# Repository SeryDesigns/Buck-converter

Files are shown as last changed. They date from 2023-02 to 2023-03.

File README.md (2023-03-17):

# Buck converter

## Project status 
Manufactured, assembled, not tested yet

## Project overview

Small synchronous buck converter PCB that can be used for small projects, the converter is based on RT6222D IC.
The input voltage can range from 4.3V to 18V, the output can be set between 0.6V to 8V.
The maximum output current is 2A though thermal dissipation should be taken into account.\
The switching frequancy of the converter is 1.4MHz.\
The IC has thermal protection in case it gets too hot, if junction temperature goes above 160°C it will shut down until the junction cools down by 20°C.

The dimension of the PCB are 33mm X 15mm, it is a 2 layers PCB with compoenents assembled only on the TOP layer

Top view - \
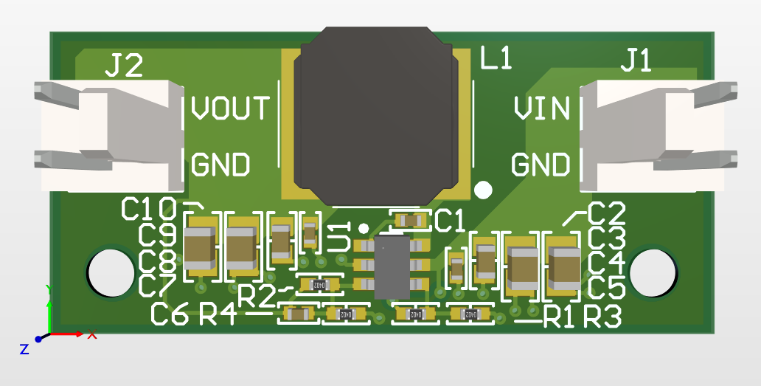
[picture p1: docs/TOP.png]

\
Bottom view -  \
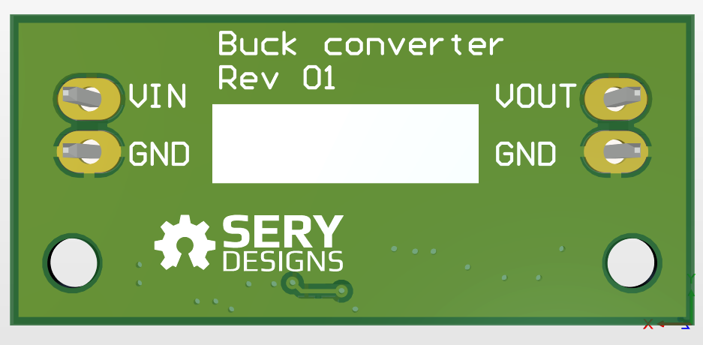
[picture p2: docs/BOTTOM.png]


I've created a short time lapse video of the design process, you can click the link below to check it out on my YouTube channel \
Buck converter PCB design in 5 minutes (time lapse) (https://youtu.be/Ut0V4XA0QD4)

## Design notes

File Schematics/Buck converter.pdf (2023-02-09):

# 12V to 5V buck converter

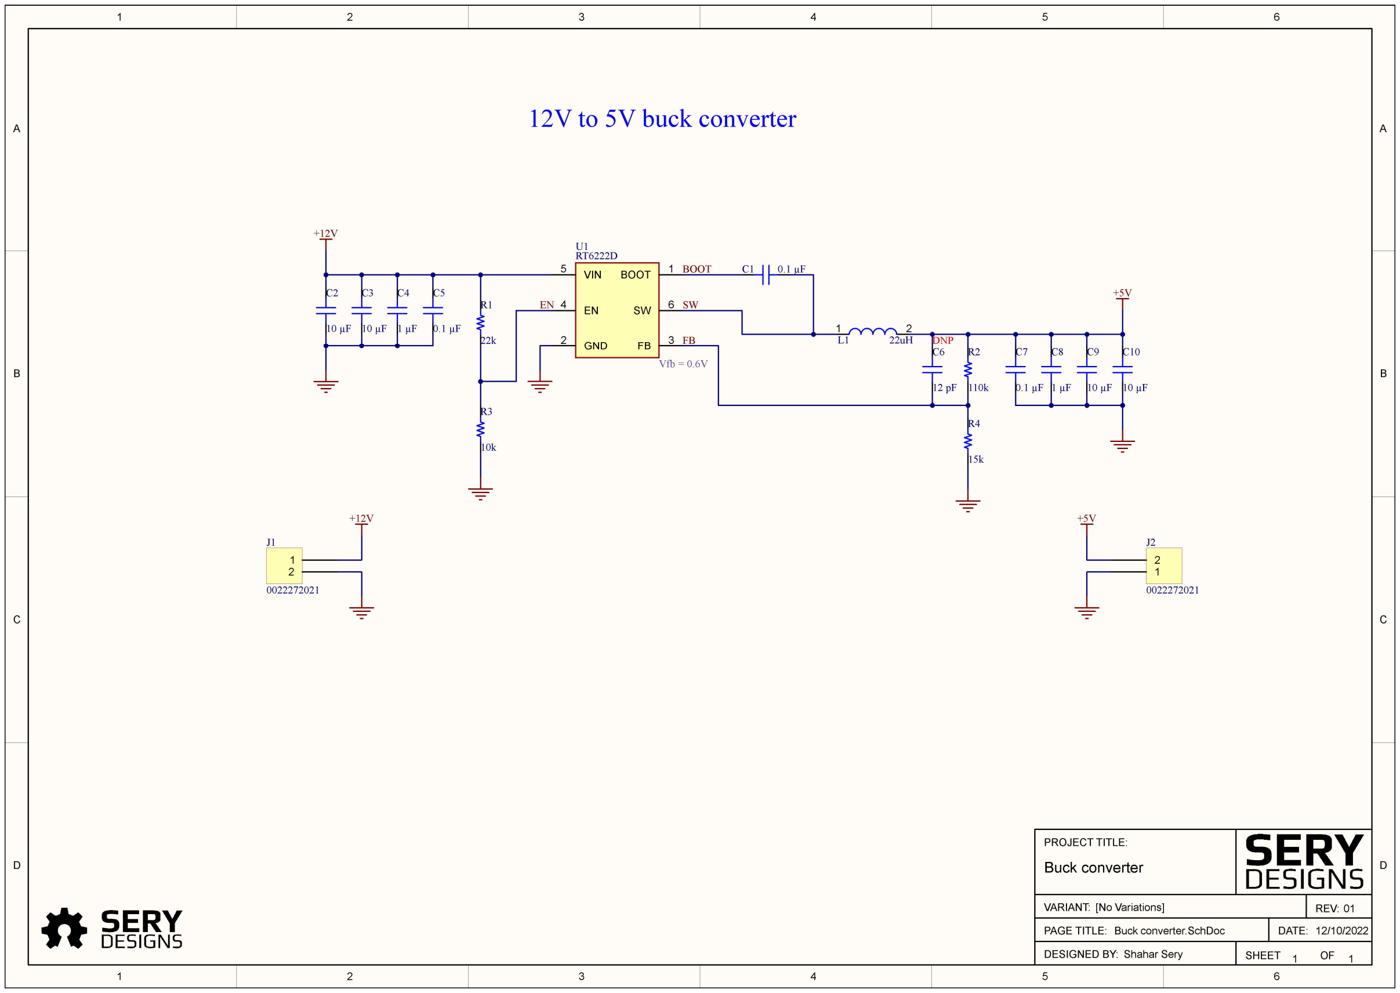
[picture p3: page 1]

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
Buck converter.SchDoc

SHEET | OF 1

REV:

PROJECT TITLE:

## Buck converter

1

VARIANT:

PAGE TITLE: | DATE:

DESIGNED BY:

[No Variations] | 01
| 12/10/2022

Shahar Sery

+12V

+5V

### 10 µF

C2

### 10 µF

C3

### 1 µF

C4

### 0.1 µF

C5

10k

R3

1 2
L1 | 22uH

15k

R4

110k

R2

### 10 µF

C10

### 10 µF

C9

### 1 µF

C8

### 0.1 µF

C7

C1 0.1 µF

### 12 pF

C6

EN

BOOT

SW

FB | DNP

1

2

J2

0022272021

1
2

J1

0022272021

+12V | +5V

Vfb = 0.6V

22k

R1

BOOT | 1
SW | 6

GND 2

EN 4

VIN 5

FB 3

U1
RT6222D

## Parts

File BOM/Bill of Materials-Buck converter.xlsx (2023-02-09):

Name | Designator | Description | Quantity | Manufacturer 1 | Manufacturer Part Number 1 | Manufacturer Lifecycle 1 | Supplier 1 | Supplier Part Number 1 | Supplier Unit Price 1 | Supplier Subtotal 1
0.1 µF | C1, C5, C7 | V | 3 |  |  |  | DigiKey | 490-GRT155R71H104KE01DCT-ND
10 µF | C2, C3, C9, C10 | V | 4 | Murata | GRM21BR61H106ME43L | Unknown | Digi-Key | 490-18664-1-ND | 0.35 | 1.4
1 µF | C4, C8 | V | 2 | Taiyo Yuden | UMK107AB7105KA-T | Unknown | Digi-Key | 587-3247-1-ND | 0.26 | 0.52
22uH | L1 | Inductor, Fixed, SMD, 22µH, 2.2A | 1 | Taiyo Yuden | NRS8040T220MJGJV | Unknown | Digi-Key | 587-3655-2-ND | 0.27472 | 274.72
22k | R1 | RES SMD 22K OHM 1% 1/16W 0402 | 1 | Bourns | CR0402-FX-2202GLF | Unknown | Digi-Key | CR0402-FX-2202GLFCT-ND | 0.1 | 0.1
75K | R2 | V | 1 | Yageo | AF0402FR-07110KL | Unknown | Digi-Key | 13-AF0402FR-07110KLCT-ND | 0.1 | 0.1
10k | R3 R4 | RES SMD 10K OHM 1% 1/16W 0402 | 1 | Yageo | RE0402FRE0710KL | Unknown | Digi-Key | 13-RE0402FRE0710KLCT-ND | 0.1 | 0.1
RT6222D | U1 | V | 1 |  |  |  | Digi-Key | N/A

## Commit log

2023-02-09 Project creation
    [Bill of Materials-Buck converter.xlsx, Buck converter.PcbDoc, Buck converter.PrjPcb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]
2023-02-09 Added gerber files
